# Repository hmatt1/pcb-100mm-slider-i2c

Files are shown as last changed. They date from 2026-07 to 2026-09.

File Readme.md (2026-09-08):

# pcb-100mm-slider-i2c

Preface:

> Hi everyone!
>
> This blog post explains how to make a PCB from scratch.
>
> It is pretty detailed on the technical side, with a goal of demistifying a lot about hardware.
>
> It also talks about my experience working with [PCBWay](https://www.pcbway.com/), who was kind enough to fund this project. They were supportive and gave me lots of freedom too. PCBWay was a great
> way to get my custom PCB design turned into reality, so I included a lot of detail on how that is done to hopefully help anyone who is new to PCB design.
>
> Thanks for reading and I hope you enjoy :) 

----

# Building a slider PCB from scratch

This [slider](https://www.adafruit.com/product/5295) from Adafruit is cool, but it has a problem. It is too small.

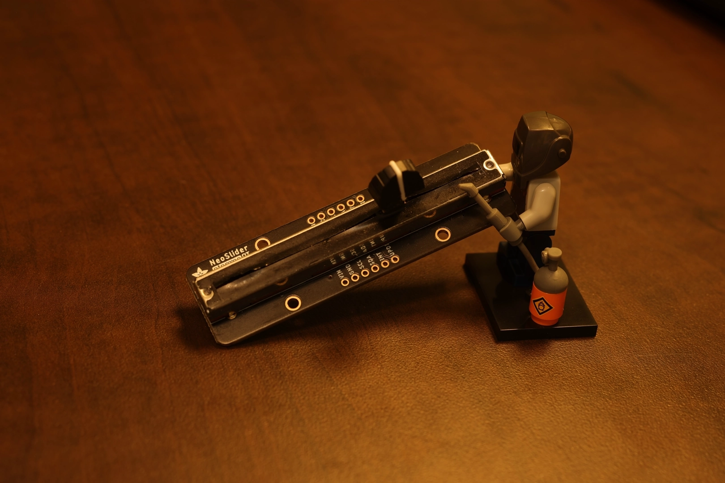
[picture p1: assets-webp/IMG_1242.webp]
Adafruit Sliders


It only has 65mm of travel distance for the slider movement.

Fortunately, it was easy to find a longer slider.

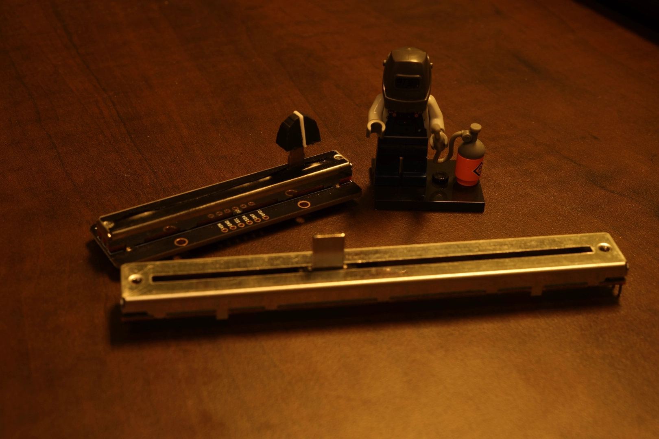
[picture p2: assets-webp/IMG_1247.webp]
new slider


This is the PTB0143-2010BPA103, in Bourn's PTB Series. It is a Low Profile Slide Potentiometer.

It has a whopping 100mm of travel! Here are some other specs:

Resistance: 10 kOhms
Tolerance: 20%	
Taper: Linear
Life: 15,000 Cycles

15k cycles is pretty nice! I've already used 3 of them. 14,997 until it starts to wear out! Wahoo!

It's an awesome part, but we still have a problem. It's not attached to a PCB, so it doesn't have an I2C interface to actually start working with it.

So obviously, I'm going to have to build that part myself. Fortunately, we have a great path forward.

After my [last blog post](https://hackaday.io/project/205240-usb-to-i2c-demo), [Aran](https://x.com/pcbway_aran) from [PCBWay](https://www.pcbway.com/) messaged me to see if [PCBWay](https://www.pcbway.com/) could sponsor my next project. 

**This was a really delightful surprise!**

I never expected to get that kind of recognition for my [last project](https://hackaday.io/project/205240-usb-to-i2c-demo). Also, I do often see [PCBWay](https://www.pcbway.com/) sponsoring YouTubers that I like, so I was excited that they reached out.

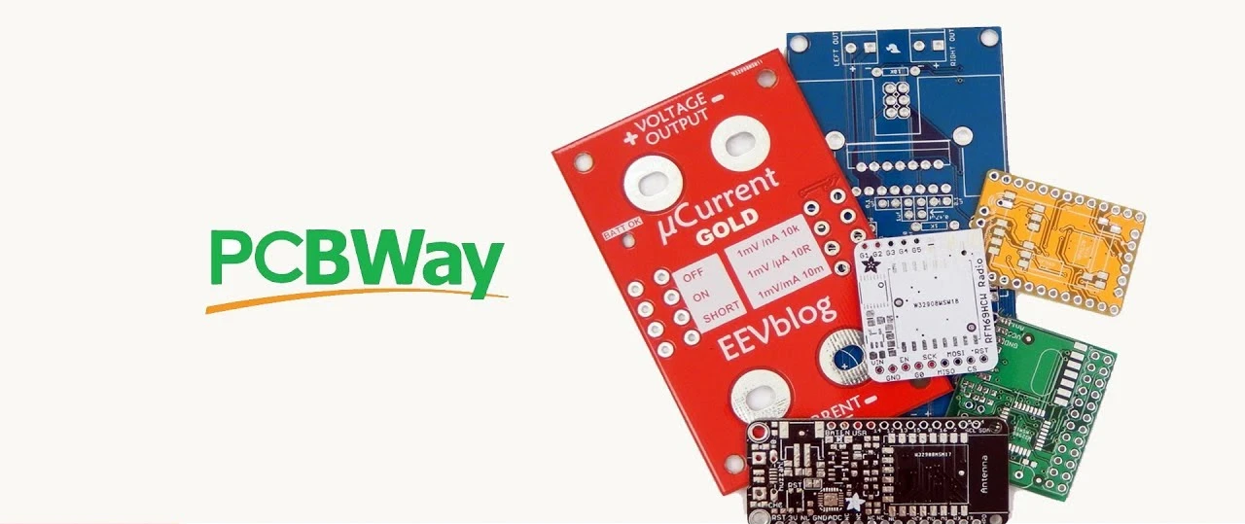
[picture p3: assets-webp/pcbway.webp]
pcbway


There's a lot to explain before we can send the design to PCBWay.

The first thing to cover is how a potentiometer works.

And to understand that, let's review a simple voltage divider.

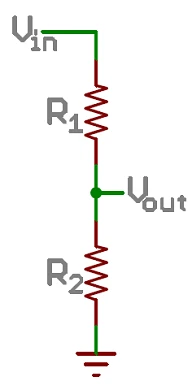
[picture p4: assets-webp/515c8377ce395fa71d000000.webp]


The formula is:

```
Vout = Vin*R2/(R1+R2) 
```

So it lets you split voltages over resistors in series.

Here is an example with some voltage numbers.

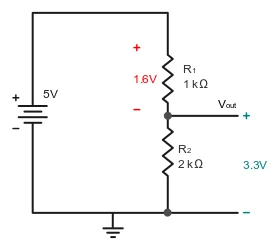
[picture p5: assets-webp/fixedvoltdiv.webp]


A slide potentiometer is basically just a variable resistor. So it is a resistor that goes between 0 and 10k ohms as you slide it.

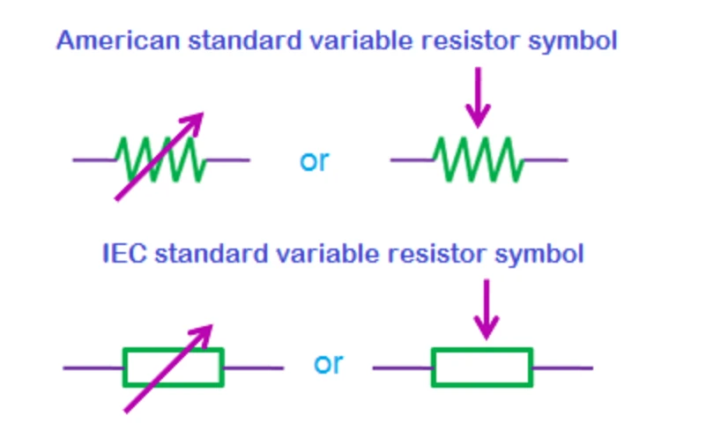
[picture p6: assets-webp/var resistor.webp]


They even show circuit diagrams like these straight in the [Bourns slider datasheet.](https://www.bourns.com/docs/Product-Datasheets/PTB.pdf)

I drew this diagram to help compare.

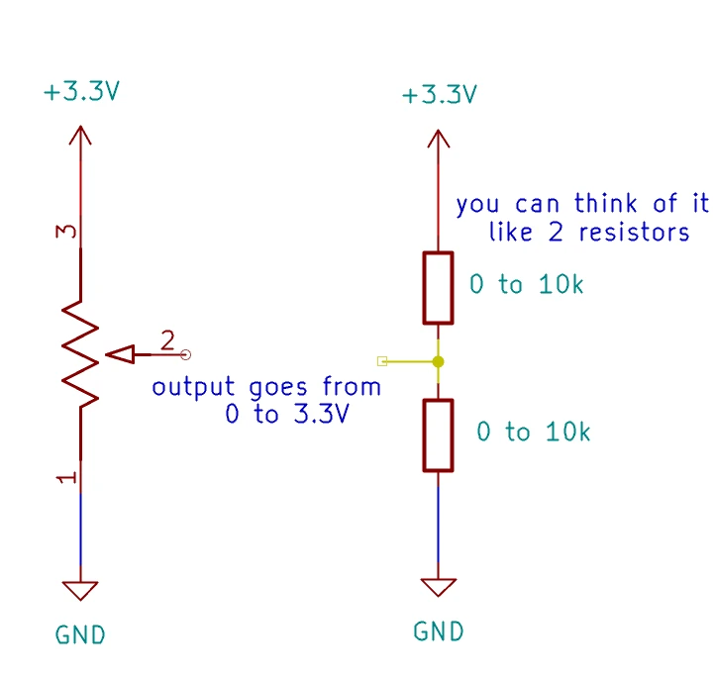
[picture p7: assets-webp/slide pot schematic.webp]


In the above image, the two resistors would always add up to 10k in total. I just didn't have a good way to represent that in the drawing.

Now that we understand the voltage divider, the next step is to add a capacitor between the wiper and ground to filter out noise.

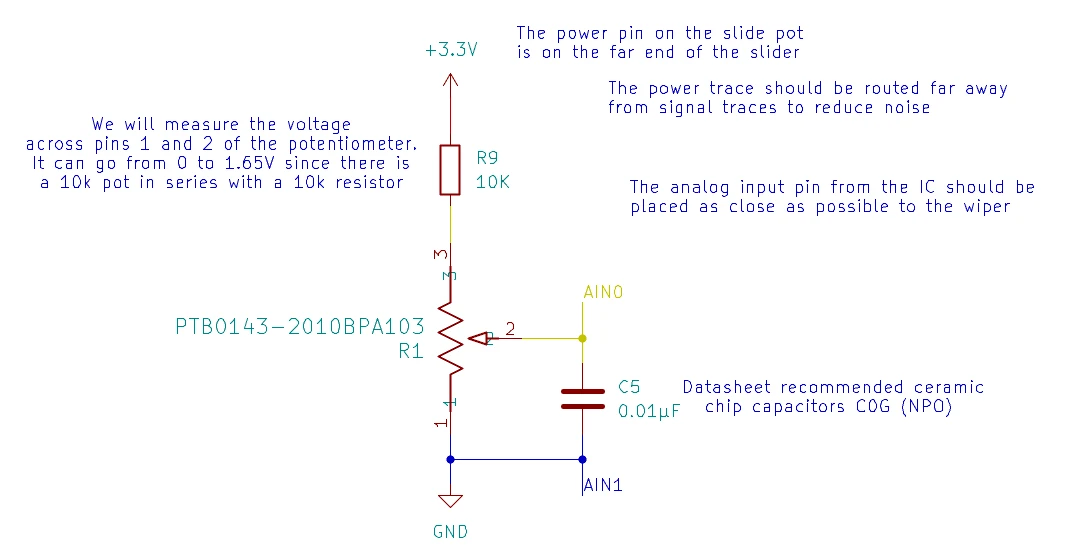
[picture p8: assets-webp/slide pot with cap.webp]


And I'm sure you're wondering now, what is the other 10k resistor doing in parallel with the circuit?

It's a long story and I'm not sure I even got it right.

First, it's nice to have a resistor in series with a slide pot, because when the wiper is all the way at one end, the resistance is 0 and it's connected to power, so there would be nothing limiting current in the case of a short due to a mistake in the circuit. It probably only needs to be 1k instead of 10k in that case.

It would have been a nice idea to add an optional jumper to bypass that resistor. But now that I think about it, I could pry it off the board and solder the pads together. Yeah, that would work fine if I want to experiment without it!

Second, which is also the main reason it's useful, is being able to use the slide pot as a rheostat instead of a voltage divider. To create a rheostat, you short the wiper to pin 3 of the slide pot. I didn't really find great explanations of this, and ended up getting confused and forgot to add a trace with a jumper to be able to try it in my circuit.

More importantly, I vibe coded this beautiful web demo to illustrate the difference (works better on desktop). Not 100% sure if the numbers it shows are right, but it's a good illustration of how the current flows.

----- DEMO HERE!!!! TODO ------

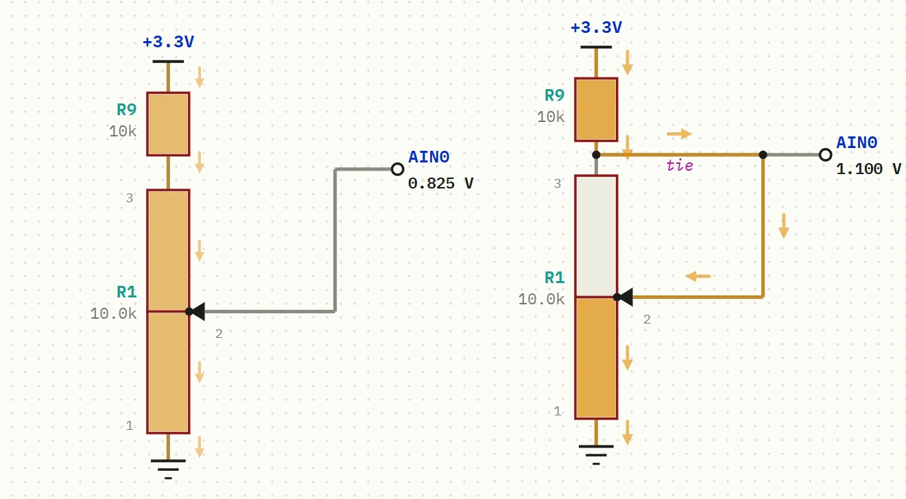
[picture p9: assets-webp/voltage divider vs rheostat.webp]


Looking back, it would have been really great to make this easier to switch between these two configurations on the final circuit! A good lesson learned.

So now that we understand how the slide potentiometer works, what do we do with it?

The answer is simple. We connect AIN0 to an ADC (Analog to Digital converter).

There's tons to choose from, but I decided to use the ADS112C04 from Texas Instruments.

Link: https://www.ti.com/product/ADS112C04

The important part was these specs:

| Parameter | Value |
|---|---|
| Resolution (Bits) | 16 |
| Sample rate (max) (ksps) | 2 |
| Interface type | I2C |
|Digital supply (min) (V) | 2.3 |
|Digital supply (max) (V) |	5.5 |

This means we can have 2,000 readings per second, which is .5ms response time to the slider moving.

I2C is a super convenient interface for connecting to the chip.

3.3V power fits comfortably in the digital voltage range for the chip.

And finally, the resolution of 16 bit readings is completely overkill. Which is exactly what I wanted!

This basically means the max value from the ADC would be 65,535. 

Remember, the slider is 100mm long.

So in a perfect world, that means if you move the slider 0.00152590219 millimeters, that would equate to changing the digital value by 1.

The real world has a lot more noise obviously.

**I love the idea that moving the slider less than .01mm would be picked up by your computer in less than 1ms.**

Now we have our chip, we need to hook it up to the rest of the circuit:

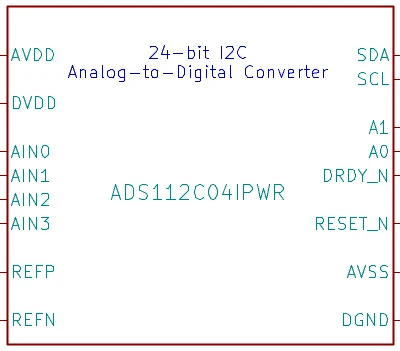
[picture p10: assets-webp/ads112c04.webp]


The analog inputs are pretty easy to connect. AIN0 will go to the wiper of the slide pot, and the rest we just tie to ground. We aren't going to both with AIN2 and AIN3 in this design, and we will just measure the voltage between AIN0 and AIN1.

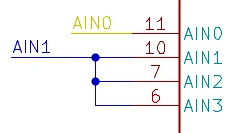
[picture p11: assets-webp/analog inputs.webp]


Next we have some data lines.

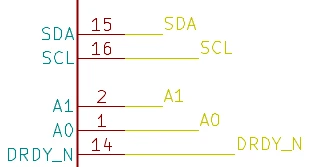
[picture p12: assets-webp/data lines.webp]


which will connect to the socket.

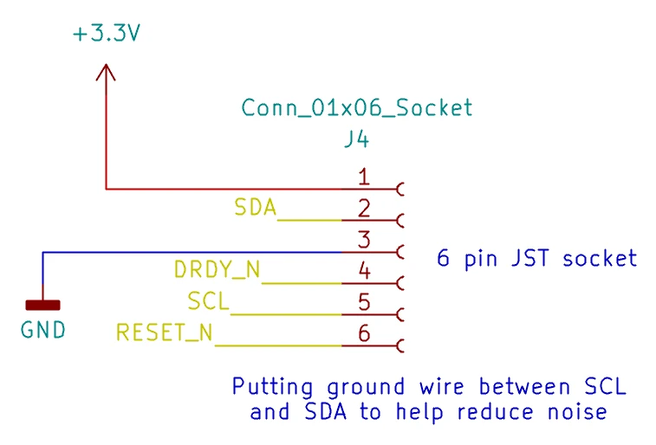
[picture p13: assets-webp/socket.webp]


The datasheet said these should be connect to power with 1k pull-up resistors. And a capacitor was added between power and ground to help with filtering noise.

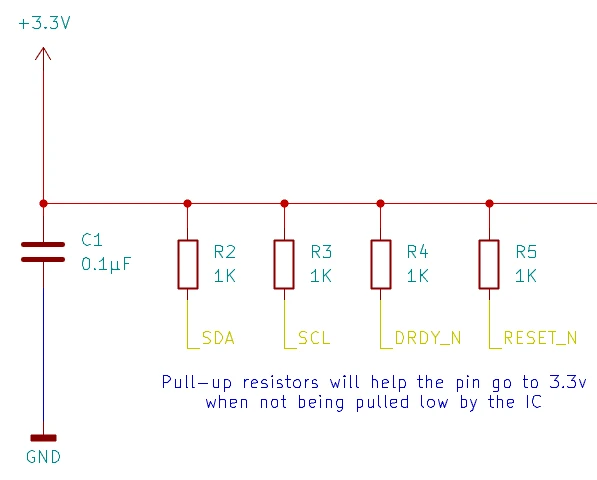
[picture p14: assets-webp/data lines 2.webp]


I also set up some jumpers to be able to configure the I2C address of the board.

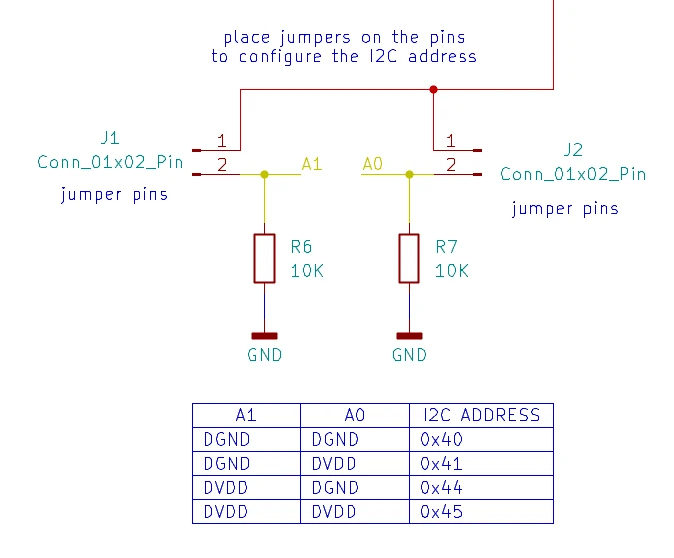
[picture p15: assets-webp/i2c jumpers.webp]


So in the full schematic, I included these tips I found in my research.

> PCB Habits for 2-layer boards:
>
> - Use 6 mil wide signal trace, 20 mil wide power traces and 13 mil drilled diameter
> - Route components, signals and power paths on layer 1 and a ground plane on layer 2
> - Adjust components for less congested routing and space signal traces far apart
> - When you need to route a cross-under on the bottom layer, make it short. When you can't make it short, add a return strap over it
> - Place decoupling capacitors as close to the power pin of the IC and with as low a loop inductance as practical
> - Use the largest size capacitor in the smallest body with a voltage rating at least 2x the intended rail application. This is usually a 22 uF MLCC capacitor.
> - On all connectors, try to allocate one return for each digital signal, if possible

And here is everything all put together!

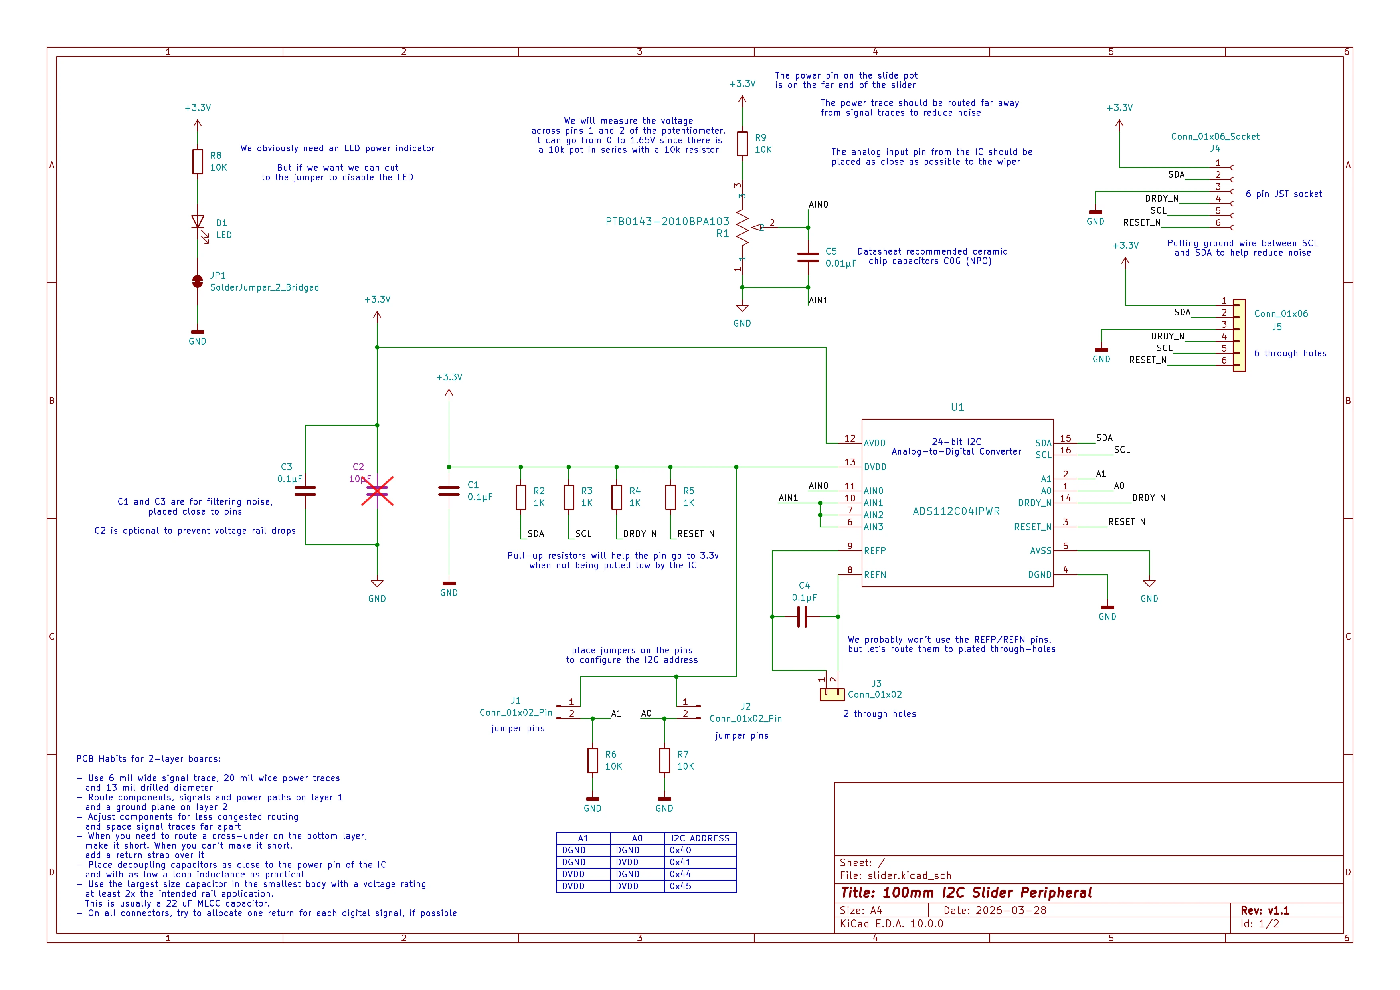
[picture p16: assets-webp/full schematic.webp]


The next thing we need to do is pick out the actually parts we want to use to mark the board. That means picking out exactly which capacitor, which resistor, etc.

I found that [partsbox](https://partsbox.com/) is free and is pretty useful to document the list of parts.

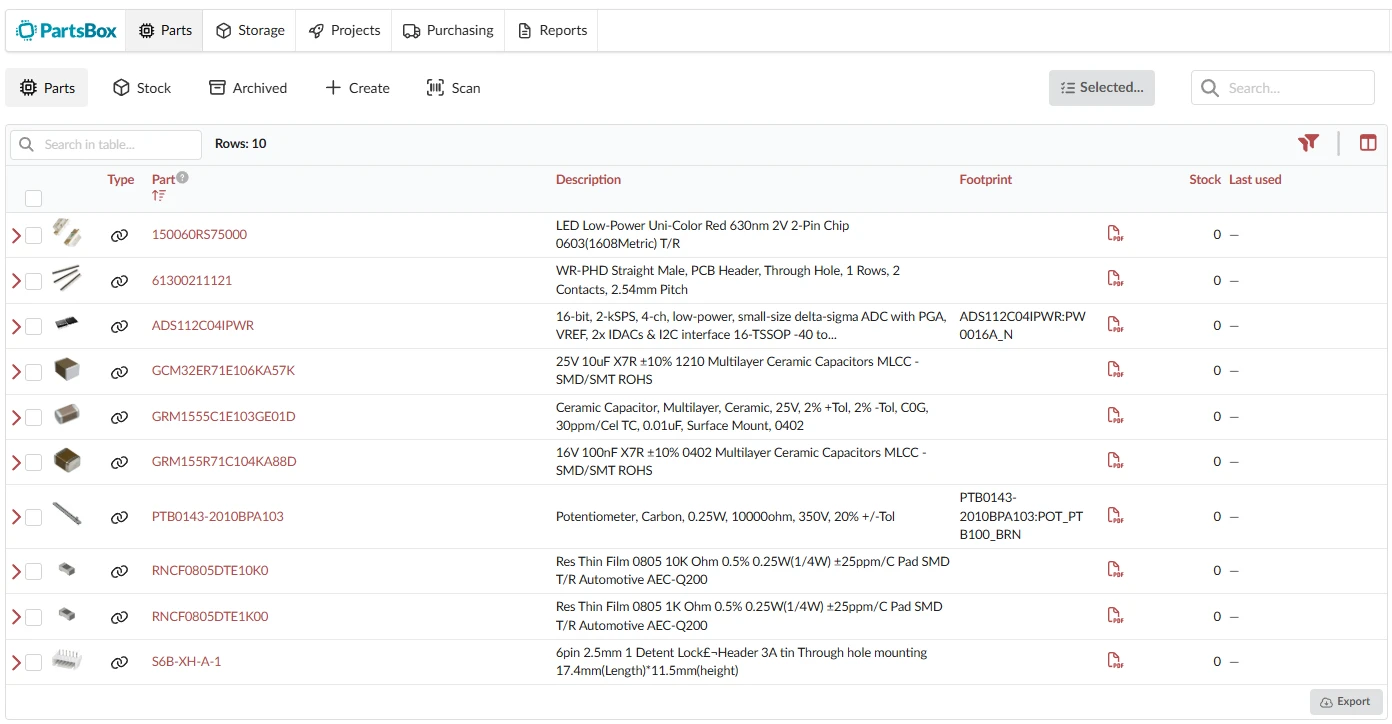
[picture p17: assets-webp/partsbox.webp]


Pretty much when I was looking for parts, I would dig through Digikey and Mouser to filter and see what parts are popular for the category.

But I also really wanted to use some super tiny capacitors on the PCB.
They are better for causing less interference in the circuit, and letting you have shorter distance between components. Also, TI specifically recommended ceramic capacitors to use with the ADC.

I found GRM1555C1E103GE01D from Murata, which is a  0.01uF, surface mount, Multilayer Ceramic Capactior. Specifically, it uses the 0402 footprint, which is about 1mm square.

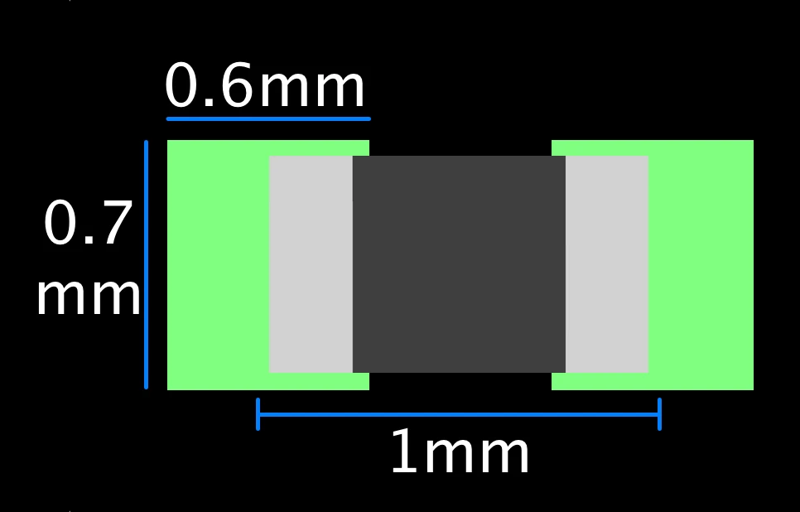
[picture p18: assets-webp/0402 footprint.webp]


It's actually amazing that [PCBWay](https://www.pcbway.com/) will solder these tiny capacitors perfectly for you. So I can use them freely on my board, and I don't have to deal with soldering them by hand.

The next part is laying out the PCB with KICAD. I can't remember if I used an AI summary or found a blog post or what for these layout guidelines, or I might have just pieces bullet points together from different sources. But it definitely help me along the way!

> **Layout Guidelines**
>
> Employing best design practices is recommended when laying out a printed-circuit board (PCB) for both analog and digital components. This recommendation generally means that the layout separates analog components [such as ADCs, amplifiers, references, digital-to-analog converters (DACs), and analog MUXs] from digital components [such as microcontrollers, complex programmable logic devices (CPLDs), field-programmable gate arrays (FPGAs), radio frequency (RF) transceivers, universal serial bus (USB) transceivers, and switching regulators]. Figure 82 shows an example of good component placement. Although Figure 82 provides a good example of component placement, the best placement for each application is unique to the geometries, components, and PCB fabrication capabilities employed. That is, there is no single layout that is perfect for every design and careful consideration must always be used when designing with any analog component.
>
> The following basic recommendations for layout of the ADS112C04 help achieve the best possible performance of the ADC. A good design can be ruined with a bad circuit layout.
>
> Separate analog and digital signals. To start, partition the board into analog and digital sections where the layout permits. Routing digital lines away from analog lines prevents digital noise from coupling back into analog signals.
>
> The ground plane can be split into an analog plane (AGND) and digital plane (DGND), but is not necessary. Place digital signals over the digital plane, and analog signals over the analog plane. As a final step in the layout, the split between the analog and digital grounds must be connected to together at the ADC.
>
> Fill void areas on signal layers with ground fill.
>
> Provide good ground return paths. Signal return currents flow on the path of least impedance. If the ground plane is cut or has other traces that block the current from flowing right next to the signal trace, another path must be found to return to the source and complete the circuit. If forced into a larger path, the chance that the signal radiates increases. Sensitive signals are more susceptible to EMI interference.
>
> Use bypass capacitors on supplies to reduce high-frequency noise. Do not place vias between bypass capacitors and the active device. Placing the bypass capacitors on the same layer as close to the active device yields the best results.
>
> Consider the resistance and inductance of the routing. Often, traces for the inputs have resistances that react with the input bias current and cause an added error voltage. Reducing the loop area enclosed by the source signal and the return current reduces the inductance in the path. Reducing the inductance reduces the EMI pickup and reduces the high-frequency impedance at the input of the device.
>
> Watch for parasitic thermocouples in the layout. Dissimilar metals going from each analog input to the sensor can create a parasitic thermocouple that can add an offset to the measurement. Differential inputs must be matched for both the inputs going to the measurement source.
>
> Analog inputs with differential connections must have a capacitor placed differentially across the inputs. Best input combinations for differential measurements use adjacent analog input lines (such as AIN0, AIN1 and AIN2, AIN3). The differential capacitors must be of high quality. The best ceramic chip capacitors are C0G (NPO) that have stable properties and low noise characteristics.

and more guidelines specific to our chip:

> **ADS112C04 layout recommendations**
>
> - Separate analog and digital signals. Partition the board into analog and digital sections where the layout permits.
> - The ground plane can be split into AGND and DGND, but is not necessary. Connect the split together at the ADC as a final step.
> - Fill void areas on signal layers with ground fill.
> - Provide good ground return paths. Return current forced into a larger loop increases radiation and EMI susceptibility.
> - Use bypass capacitors on supplies. No vias between the bypass capacitor and the active device, same layer, as close as possible.
> - Consider trace resistance and inductance. Input trace resistance reacts with input bias current and adds an error voltage.
> - Watch for parasitic thermocouples. Match the dissimilar-metal transitions on both differential inputs.
> - Place a differential capacitor across differential inputs. Use adjacent input pairs (AIN0/AIN1, AIN2/AIN3) and C0G (NPO) dielectric.

-----

Anyway, in Kicad, you want to set up each part in the schematic with the symbol properties.

So if I a want to assign C1 to a part, I would open up symbol properties and fill them out.

It looks like this:

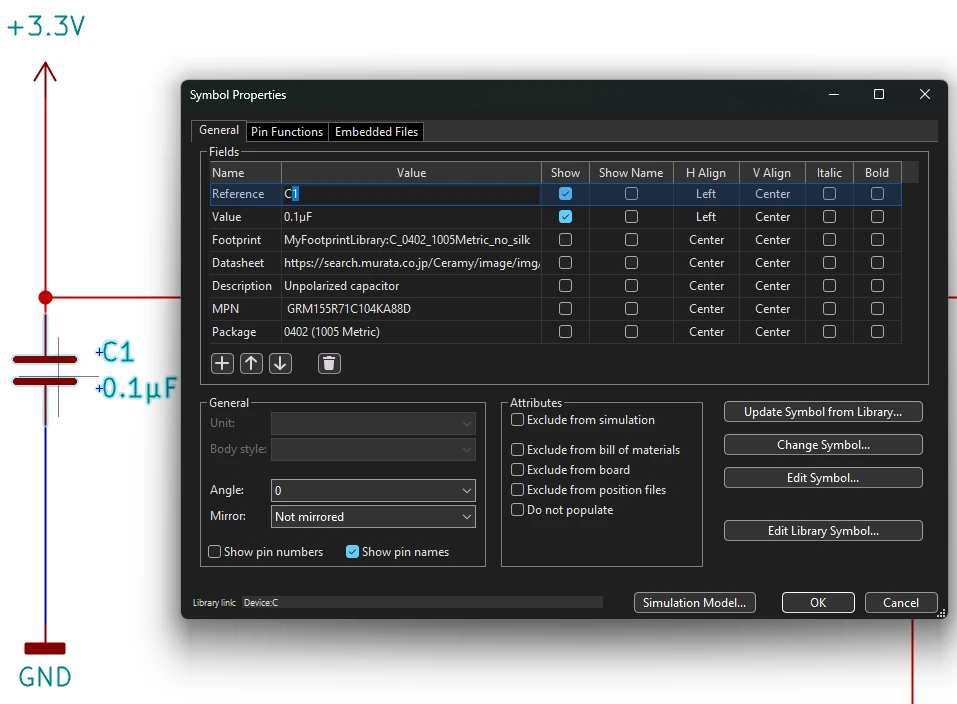
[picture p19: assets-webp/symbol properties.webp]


This is super important because it will know what footprints to use with which parts of the schematic. And it will let the PCBWay Kicad plugin export the BOM automatically. But more on that later!

So basically, we are tying these things together:

```
Schematic Symbol -> Part Number -> Footprint 
```

So if you look at the menu in Kicad, it should start making sense.

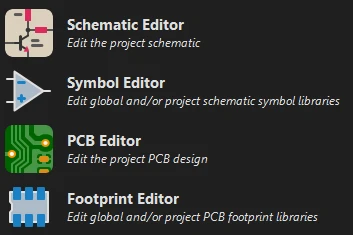
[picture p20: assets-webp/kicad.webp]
kicad


Schematic is the actual diagram. Symbols are symbols on the diagram. Footprints are the geometry that will attach specific parts to the board.

And then PCB Editor is the fun part, where we design the layout of the board itself.

You import the schematic into the PCB Editor, and then draw traces (wires) to connect everything together.

Kicad already knows how your schematic is set up, so it makes sure you can't accidentally connect things that aren't connected in the schematic.

Before you jump into creating the whole PCB design, you need to set up the design rules.

PCBWay has a nice article about Design Rules, and even have the files available to download and import the rules into Kicad.

[PCBWay Design Rules](https://www.pcbway.com/pcb_prototype/PCB_Design_Rule_Check.html)

You'll also want to pay attention to what your manufacturer has available, so you can make sure the rules are correct for that too.

For example, PCBWay lets you select the min spacing and min hole size when [ordering online](https://www.pcbway.com/orderonline.aspx).



So if your min hole size is .3mmm, you don't want to design a PCB with smaller holes  than that. Basically, you want to know all the dimensions of everything in your design.

I think it's a really good idea to pick which manufacturer you want to make your PCB before doing the design. Read through all the options available, so you can ensure your design will meet what they are capable of building.

If you think back to the 1mm capacitor I picked out as a part, not everyone is going to be able to solder that to a board. 

I did look up the [assembly capabilities](https://www.pcbway.com/pcb_prototype/PCB_assembly_Capabilities.html) for PCBWay, to verify this in the documentation:

> we can accept components as small as 01005, 0201,0402.

This means they will deal with my super tiny capacitor! I do not want to try to solder that.

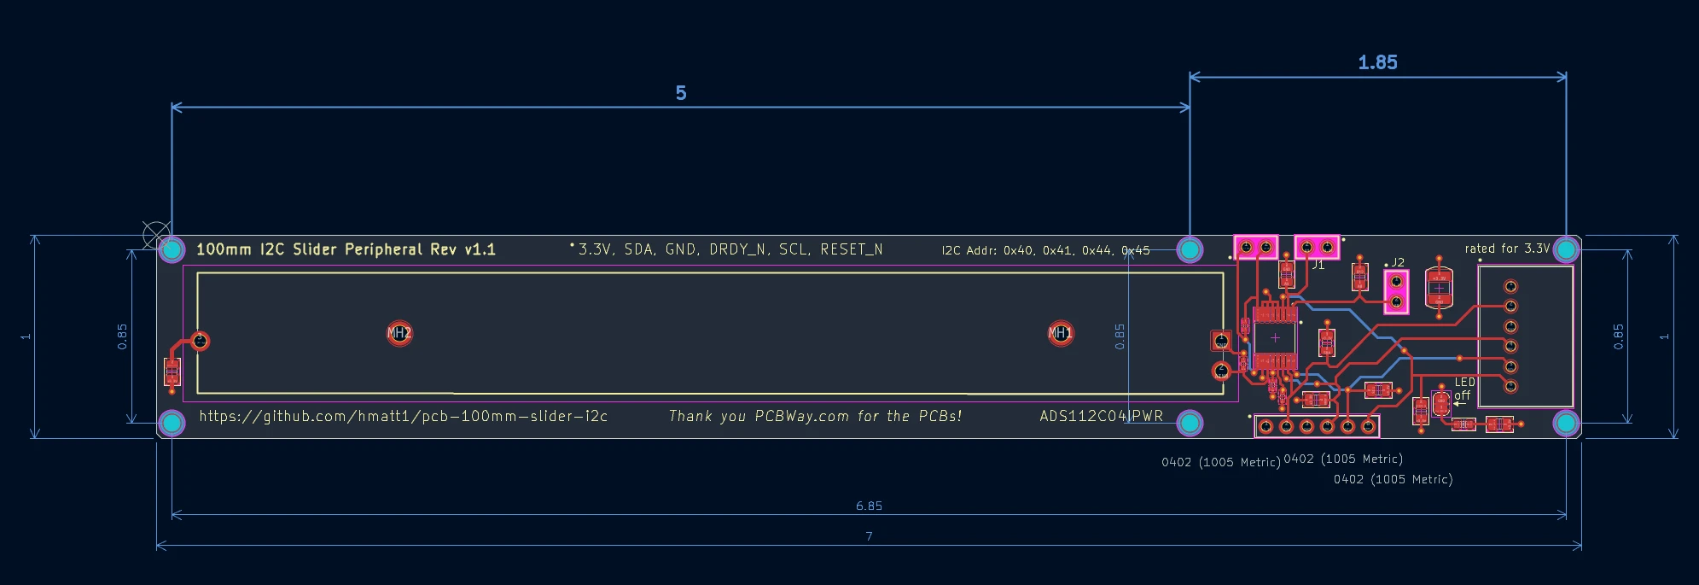
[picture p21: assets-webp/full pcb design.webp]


And here is the rendered version:

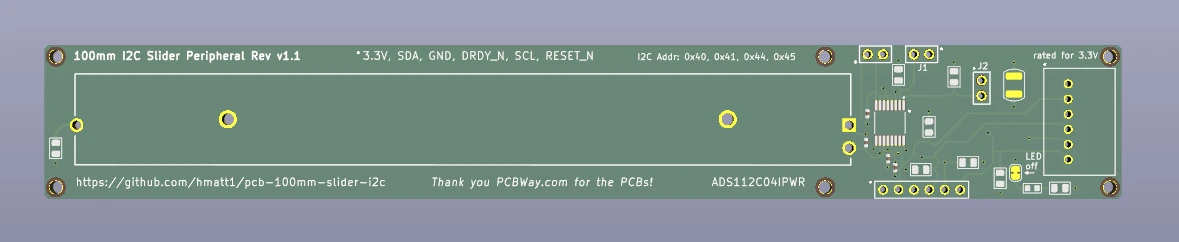
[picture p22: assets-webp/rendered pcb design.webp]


You can do 3D models of the parts too, but I decided to skip that and trust the footprints. It is a good idea though if you want to take time to verify things will fit together properly in real life.

For exporting files for PCBWay, you can use the [PCBWay Fabrication Toolkit plug-in for Kicad](https://github.com/pcbway/PCBWay-Plug-in-for-Kicad).

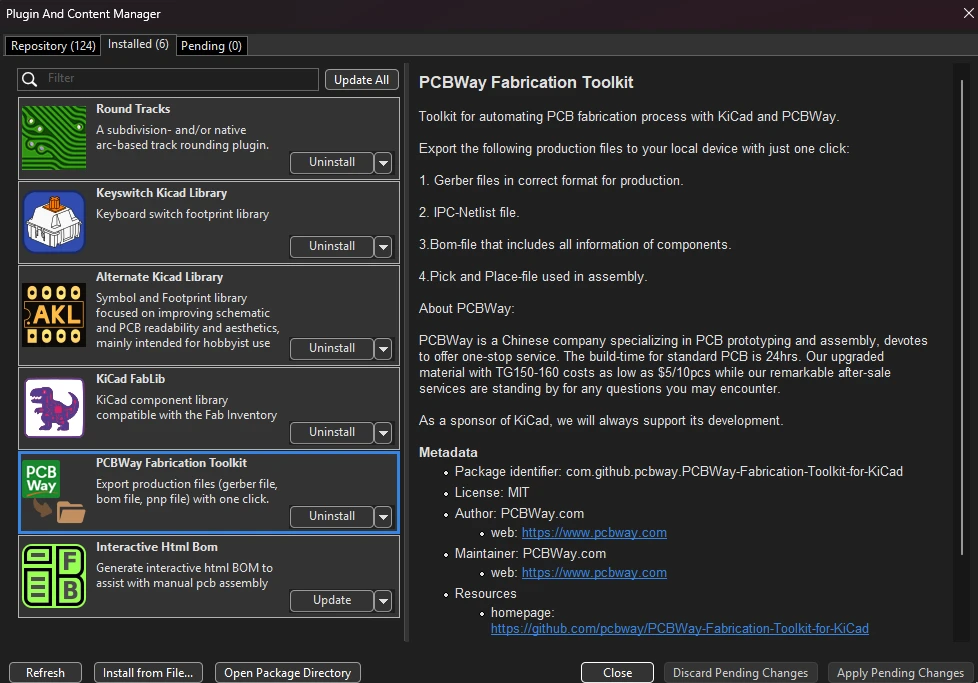
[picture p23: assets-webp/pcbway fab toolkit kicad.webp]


You can use when you're in the PCB Editor from the Tools menu.

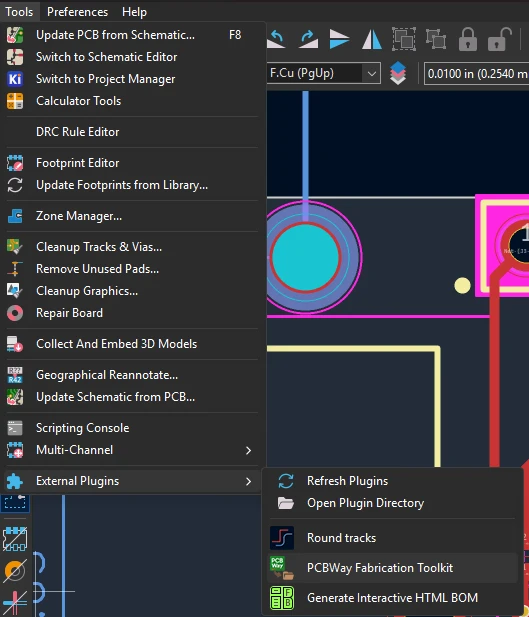
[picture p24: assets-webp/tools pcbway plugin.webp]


One click and it will export all the files you need.

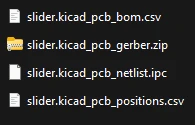
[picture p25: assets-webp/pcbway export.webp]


Just upload the files to PCBWay and you're good to go.

I'll share what my order looked like here too:

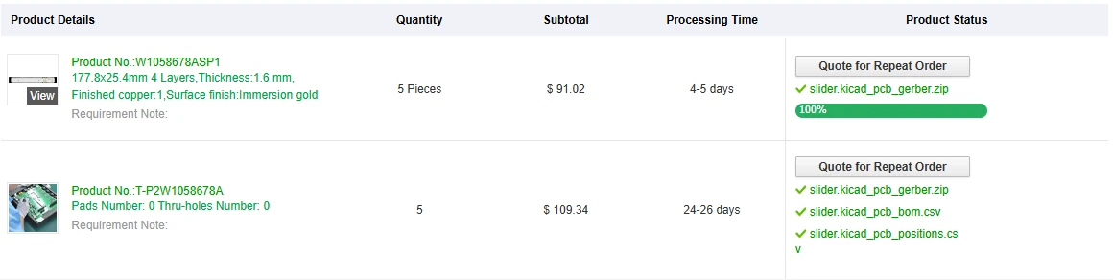
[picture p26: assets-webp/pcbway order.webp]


The order includes all the parts and assembly too. I will be getting 5 boards, fully assembled, ready to test out as soon as they arrive at my house! I don't have to mess with any soldering and PCBWay went through the work of sourcing all the different parts. By the way, I did only use [Digikey](https://www.digikey.com/) to find what parts they have in stock. PCBWay ordered parts directly from them for my board, and that was included in the cost of the order.

It was nice that I could just focus on the design.

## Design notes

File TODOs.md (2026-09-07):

  Here is your master checklist of everything left to do to wrap up the blog post:

  ### 📝 Blog Post & Content TODOs

  [ ] Embed the Interactive Demo: Replace the ----- DEMO HERE!!!! TODO ------ marker at line 108 with the index.html
  React demo we polished up.
  [ ] Write the Software/Testing Section: The post currently ends after the PCBWay order. Write a new section
  explaining how you hooked it up to your computer.
  [ ] Add Python Script Snippet: Include the Python code you used to read the I2C data from the ADC.
  [ ] Add a Conclusion: Write a wrap-up paragraph showing that the slider works, summarizing the <1ms / 16-bit
  accuracy results you hyped up earlier, and thanking the reader/PCBWay.
  [ ] Add https://kicanvas.org to host it

  ### 📸 Photography Checklist

  [ ] The Batch Shot: A picture of all 5 assembled boards laid out together (the classic "they arrived!" shot).
  [x] The "Hero" Shot: A nice, clean shot of a single fully assembled PCB with the massive 100mm Bourns slider
  attached.
  [x] The 0402 Capacitor Closeup: A macro shot of the tiny 1mm capacitor (put a coin, ruler, or pen tip next to it
  for scale to show off the assembly job).
  [x] The ADC Chip (ADS112C04): A closeup of the Texas Instruments chip soldered onto the board.
  [x] The I2C Address Jumpers: A photo showing the jumper pads, ideally with one bridged with solder to show how you
  configure the address.
  [x] The "Action" Shot: A photo of the board wired up and plugged into your computer/microcontroller setup to
  introduce the Python software section.
  [x] Python Output Screenshot: A screenshot of your terminal/console showing the live data streaming in from the
  slider.

  ### Sharing

  [ ]  Hackaday post
  [ ]  Reddit post
  [ ]  PCBWay review
  [ ]  OSHWA Certification

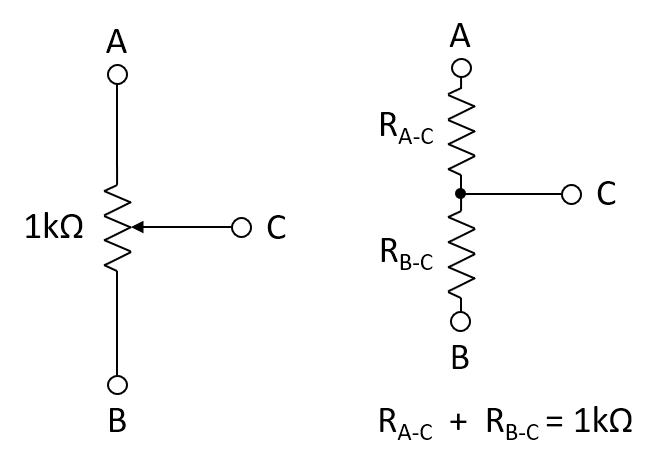
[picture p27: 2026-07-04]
assets/potentiometer-symbol-2.png

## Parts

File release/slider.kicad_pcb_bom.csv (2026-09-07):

Designator | Quantity | Value | Footprint | Package | MPN | DNP | Mount_Type | Description | KiLib_Generator | Sim.Pins
C1, C3, C4 | 3 | 0.1µF | C_0402_1005Metric_no_silk | 0402 (1005 Metric) | GRM155R71C104KA88D |  | smt | Unpolarized capacitor | SMD_2terminal_chip_molded
C5 | 1 | 0.01µF | C_0402_1005Metric_no_silk | 0402 (1005 Metric) | GRM1555C1E103GE01D |  | smt | Unpolarized capacitor | SMD_2terminal_chip_molded
D1 | 1 | LED | LED_0603_1608Metric | 0603 (1608 Metric) | 150060RS75000 |  | smt | Light emitting diode |  | 1=K 2=A
J1, J2 | 2 | Conn_01x02_Pin | 61300211121 | Through Hole | 61300211121 |  | tht | Generic connector, single row, 01x02, script generated
J4 | 1 | Conn_01x06_Socket | CONN_S6B-XH-A-1_JST | Through Hole | S6B-XH-A-1 |  | tht | Generic connector, single row, 01x06, script generated
R1 | 1 | PTB0143-2010BPA103 | PTB01432010BPB103 | Through Hole | PTB0143-2010BPA103 |  | tht
R2, R3, R4, R5 | 4 | 1K | R_0805_2012Metric | 0805 (2012 Metric) | RNCF0805DTE1K00 |  | smt | Resistor
R6, R7, R8, R9 | 4 | 10K | R_0805_2012Metric | 0805 (2012 Metric) | RNCF0805DTE10K0 |  | smt | Resistor
U1 | 1 | ADS112C04IPWR | SOP65P640X120-16N | TSSOP (16) | ADS112C04IPWR |  | smt

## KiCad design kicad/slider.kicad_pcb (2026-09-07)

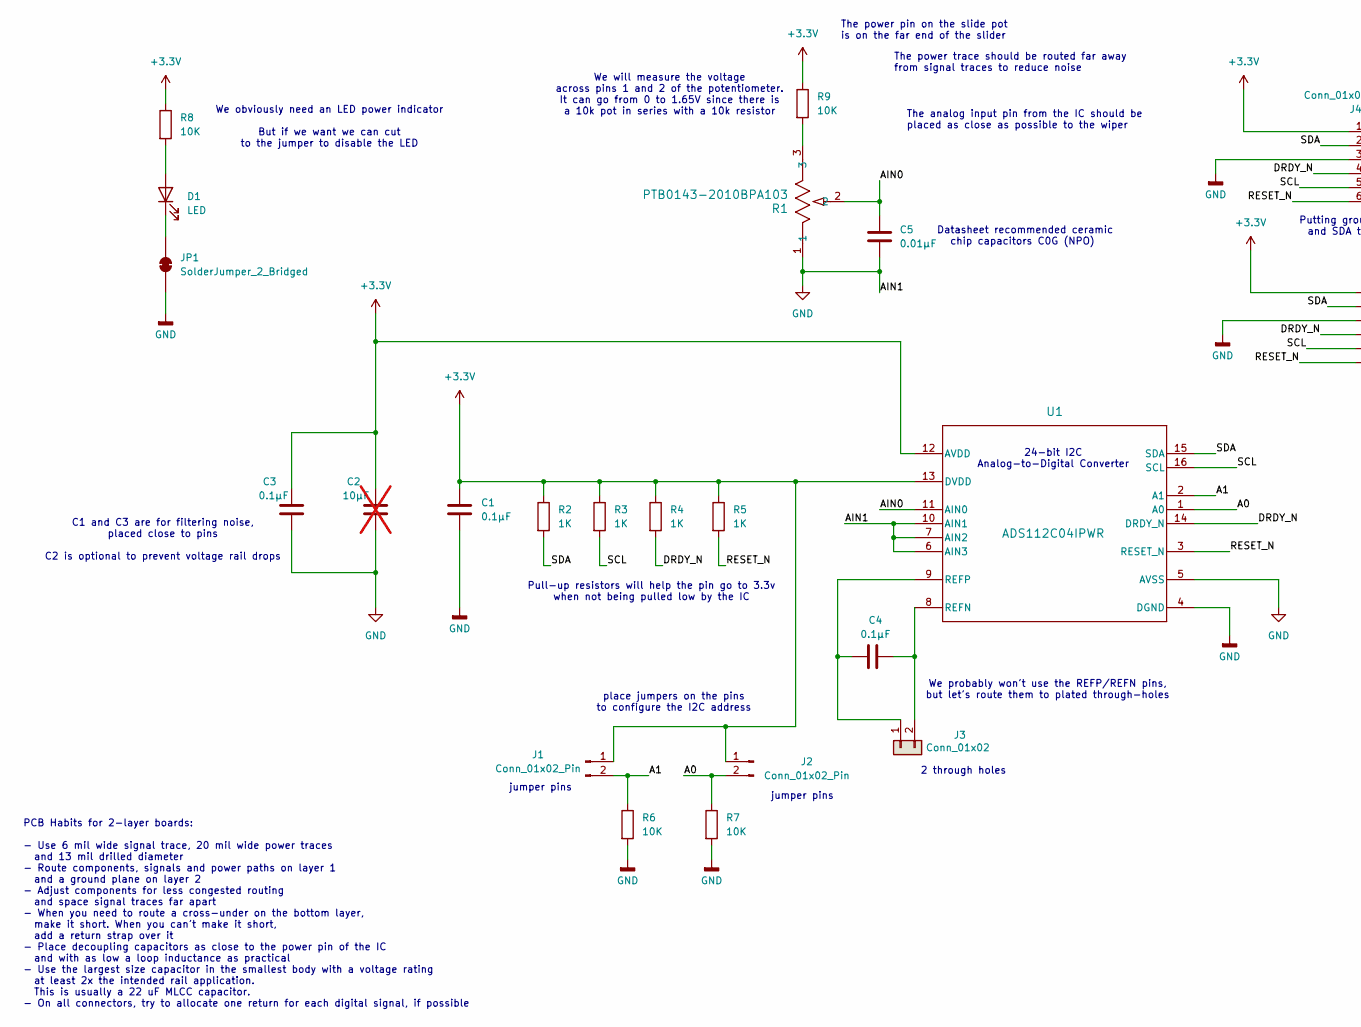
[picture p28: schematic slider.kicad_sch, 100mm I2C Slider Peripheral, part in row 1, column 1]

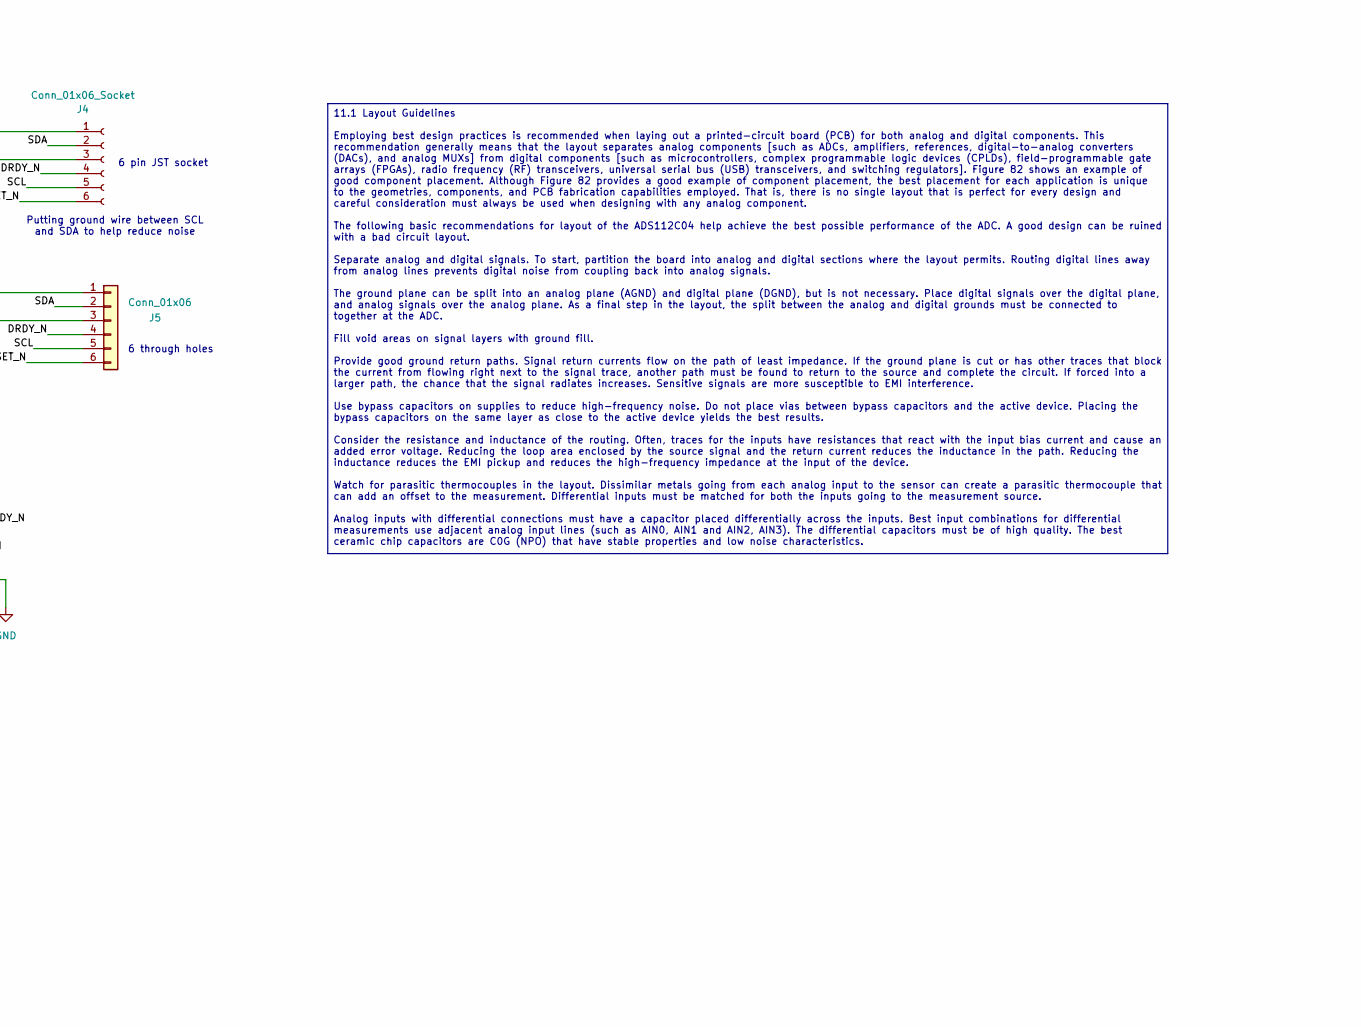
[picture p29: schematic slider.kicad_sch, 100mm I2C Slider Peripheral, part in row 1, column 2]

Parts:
C1, C3, C4: 0.1µF; C_0402_1005Metric_no_silk; MPN GRM155R71C104KA88D
C2: 10µF; C_1210_3225Metric; MPN GCM32ER71E106KA57K; not fitted
C5: 0.01µF; C_0402_1005Metric_no_silk; MPN GRM1555C1E103GE01D
D1: LED; LED_0603_1608Metric; MPN 150060RS75000
J1, J2: Conn_01x02_Pin; 61300211121; MPN 61300211121
J3: Conn_01x02; 61300211121
J4: Conn_01x06_Socket; CONN_S6B-XH-A-1_JST; MPN S6B-XH-A-1
J5: Conn_01x06; CONN06_6130_15P24X2P54_WRE
JP1: SolderJumper_2_Bridged; SolderJumper-2_P1.3mm_Bridged_RoundedPad1.0x1.5mm
R1: PTB0143-2010BPA103; PTB01432010BPB103; MPN PTB0143-2010BPA103
R2, R3, R4, R5: 1K; R_0805_2012Metric; MPN RNCF0805DTE1K00
R6, R7, R8, R9: 10K; R_0805_2012Metric; MPN RNCF0805DTE10K0
U1: ADS112C04IPWR; SOP65P640X120-16N; MPN ADS112C04IPWR

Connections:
+3.3V: C1.1, C2.1, C3.1, J1.1, J2.1, J4.1, J5.1, R2.1, R3.1, R4.1, R5.1, R8.1, R9.1, U1.12 (AVDD), U1.13 (DVDD)
/A0: J2.2, R7.1, U1.1 (A0)
/A1: J1.2, R6.1, U1.2 (A1)
/AIN0: C5.2, R1.2, U1.11 (AIN0)
/DRDY_N: J4.4, J5.4, R4.2, U1.14 (DRDY_N)
/RESET_N: J4.6, J5.6, R5.2, U1.3 (RESET_N)
/SCL: J4.5, J5.5, R3.2, U1.16 (SCL)
/SDA: J4.2, J5.2, R2.2, U1.15 (SDA)
GND: C1.2, C2.2, C3.2, C5.1, J4.3, J5.3, JP1.2 (B), R1.1, R6.2, R7.2, U1.4 (DGND), U1.5 (AVSS), U1.6 (AIN3), U1.7 (AIN2), U1.10 (AIN1)
unnamed: D1.2 (A), R8.2
unnamed: D1.1 (K), JP1.1 (A)
unnamed: C4.1, J3.1, U1.9 (REFP)
unnamed: C4.2, J3.2, U1.8 (REFN)
unnamed: R1.3, R9.2

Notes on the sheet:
C1 and C3 are for filtering noise, placed close to pins C2 is optional to prevent voltage rail drops
Pull-up resistors will help the pin go to 3.3v when not being pulled low by the IC
The analog input pin from the IC should be placed as close as possible to the wiper
place jumpers on the pins to configure the I2C address
2 through holes
Putting ground wire between SCL and SDA to help reduce noise
jumper pins
6 pin JST socket
We probably won't use the REFP/REFN pins, but let's route them to plated through-holes
The power trace should be routed far away from signal traces to reduce noise
We will measure the voltage across pins 1 and 2 of the potentiometer. It can go from 0 to 1.65V since there is a 10k pot in series with a 10k resistor
6 through holes
The power pin on the slide pot is on the far end of the slider
We obviously need an LED power indicator But if we want we can cut to the jumper to disable the LED
PCB Habits for 2-layer boards: - Use 6 mil wide signal trace, 20 mil wide power traces and 13 mil drilled diameter - Route components, signals and power paths on layer 1 and a ground plane on layer 2 - Adjust components for less congested routing and space signal traces far apart - When you need to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
24-bit I2C Analog-to-Digital Converter
Datasheet recommended ceramic chip capacitors C0G (NPO)
11.1 Layout Guidelines Employing best design practices is recommended when laying out a printed-circuit board (PCB) for both analog and digital components. This recommendation generally means that the layout separates analog components [such as ADCs, amplifiers, references, digital-to-analog conver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

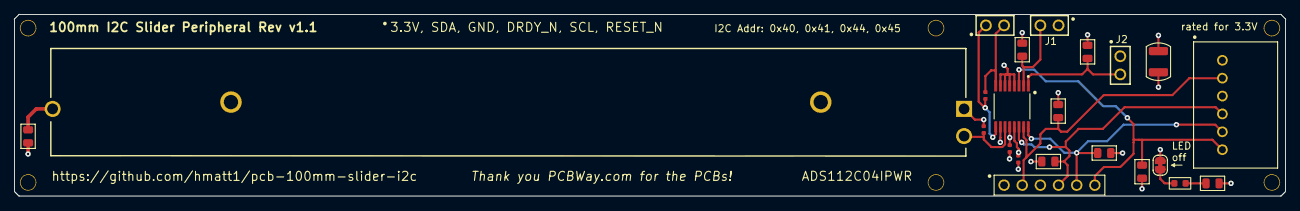
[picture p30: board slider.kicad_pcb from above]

Board: 4 copper layers, 177.8 x 25.4 mm, 28 parts (0 on the bottom side), 14 nets.

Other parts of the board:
REF1**, REF2**, REF3**, REF4**, REF5**, REF6**: MountingHole_M2_new

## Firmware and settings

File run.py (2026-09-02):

# go read https://github.com/hmatt1/adafruit-FT232H-my-demo to learn how to set this up!

import usb

print("usb:")
dev = usb.core.find(idVendor=0x0403, idProduct=0x6014)
print(dev)

from pyftdi.ftdi import Ftdi

# Just to display debugging info
#print("ftdi:")
#Ftdi().open_from_url('ftdi:///?')

def lower_ftdi_latency(i2c, ms=1):
    seen = set()
    stack = [i2c]
    while stack:
        obj = stack.pop()
        if id(obj) in seen:
            continue
        seen.add(id(obj))
        if hasattr(obj, "set_latency_timer"):
            obj.set_latency_timer(ms)
            return True
        if hasattr(obj, "__dict__"):
            stack.extend(vars(obj).values())
    return False

import os
is_blinka_env_set = os.environ["BLINKA_FT232H"]
print(f"is_blinka_env_set: {is_blinka_env_set}")


import board
import time
import digitalio

import busio

print("--- Full Board Inspection ---")
print(f"board_id: {board.board_id}")
print(f"board_key: {board.board_key}")
print(f"board_module: {board.board_module}")
print(f"pin: {board.pin}")
print(dir(board))


led = digitalio.DigitalInOut(board.C0)
led.direction = digitalio.Direction.OUTPUT


i = 0
while i < 10:
    led.value = False
    time.sleep(0.1)
    led.value = True
    time.sleep(0.1)
    i = i + 1

# Backpack I2C Address (defined in Adafruit docs, and etched on the board)
ADDR = 0x70

print("i2c setup...")
i2c = busio.I2C(board.SCL, board.SDA, frequency=400_000)

while not i2c.try_lock():
    print("trying...")
    pass

if lower_ftdi_latency(i2c, 1):
    print("FTDI latency timer set to 1 ms")
else:
    print("could not reach the FTDI handle; still at 16 ms default")

addresses = i2c.scan()

for x in addresses:
    print(f"-> Device found at address: {hex(x)} (Decimal: {x})")
    if x == ADDR:
        print(f"   *** ADDR {hex(ADDR)} detected! ***")


# I2C slave address of the ADS112C04. This is set by the device's two
# address pins (both tied to GND in this wiring) and confirmed by the bus
# scan coming back with 0x40. It identifies the chip on the bus and is a
# separate thing from the command bytes below.
ADS_ADDR = 0x40

# All command bytes come from the command format in datasheet section 8.5.3.
# Each command is a single byte. Bits shown as x are don't-care, set to 0.

# RESET: format 0000 011x  ->  0000 0110
RESET = 0x06

# RREG, read a register: format 0010 rrxx
# rr is the 2-bit register number sitting in bits 3 and 2. xx are don't-care.
RREG0 = 0x20   # 0010 0000   rr = 00, register 0
RREG1 = 0x24   # 0010 0100   rr = 01, register 1
RREG2 = 0x28   # 0010 1000   rr = 10, register 2
RREG3 = 0x2C   # 0010 1100   rr = 11, register 3

# WREG, write a register: format 0100 rrxx, followed by the data byte.
# Same rr placement as RREG; only the top nibble changes from 0010 to 0100.
WREG0 = 0x40   # 0100 0000   rr = 00, register 0
WREG1 = 0x44   # 0100 0100   rr = 01, register 1
WREG2 = 0x48   # 0100 1000   rr = 10, register 2
WREG3 = 0x4C   # 0100 1100   rr = 11, register 3

def ads_read_reg(i2c, rreg_cmd):
    result = bytearray(1)
    i2c.writeto_then_readfrom(ADS_ADDR, bytes([rreg_cmd]), result)
    return result[0]

def ads_write_reg(i2c, wreg_cmd, value):
    i2c.writeto(ADS_ADDR, bytes([wreg_cmd, value]))

print("i2c resetting...")
i2c.writeto(ADS_ADDR, bytes([RESET]))
print("i2c after reset (expect 0x0):")
print(f"  reg0 -> {hex(ads_read_reg(i2c, RREG0))}")
print(f"  reg1 -> {hex(ads_read_reg(i2c, RREG1))}")
print(f"  reg2 -> {hex(ads_read_reg(i2c, RREG2))}")
print(f"  reg3 -> {hex(ads_read_reg(i2c, RREG3))}")

time.sleep(0.1)

print("i2c writing...")

ads_write_reg(i2c, WREG0, 0x01)
ads_write_reg(i2c, WREG1, 0x04)

print("i2c after writing config:")
print(f"  reg0 -> {hex(ads_read_reg(i2c, RREG0))}")
print(f"  reg1 -> {hex(ads_read_reg(i2c, RREG1))}")

time.sleep(0.1)

START = 0x08    # START/SYNC: 0000 1000, kicks off one conversion
RDATA = 0x10    # RDATA:      0001 0000, reads the latest conversion result

AVDD = 3.3      # set to your measured AVDD pin voltage

def ads_read_data(i2c):
    result = bytearray(2)
    i2c.writeto_then_readfrom(ADS_ADDR, bytes([RDATA]), result)
    return (result[0] << 8) | result[1]     # combine the two bytes into 16 bits

def ads_data_ready(i2c):
    return ads_read_reg(i2c, RREG2) & 0x80   # DRDY is bit 7 of register 2

def ads_read_voltage(i2c):
    i2c.writeto(ADS_ADDR, bytes([START]))    # start one conversion
    while not ads_data_ready(i2c):           # wait until the result is ready
        time.sleep(0.005)
    raw = ads_read_data(i2c)
    if raw & 0x8000:                          # 16-bit two's complement -> signed
        raw -= 0x10000
    return raw * AVDD / 32768                 # scale to volts against the reference

# AIN0 - AIN1, gain 1, PGA bypassed, AVDD as reference
ads_write_reg(i2c, WREG0, 0x01)
ads_write_reg(i2c, WREG1, 0x04)



import threading
import collections
import matplotlib.pyplot as plt
from matplotlib.animation import FuncAnimation

GAIN = 1

# reg0: AIN0-AIN1, gain 1, PGA bypassed
# reg1: 0xDC = turbo, 2000 SPS, continuous conversion, AVDD reference
ads_write_reg(i2c, WREG0, 0x01)
ads_write_reg(i2c, WREG1, 0xDC)
i2c.writeto(ADS_ADDR, bytes([START]))      # start continuous conversions once

def ads_read_latest(i2c):
    raw = ads_read_data(i2c)               # RDATA only: no START, no DRDY poll
    if raw & 0x8000:
        raw -= 0x10000
    return raw * AVDD / GAIN / 32768


last_report = time.monotonic()
read_count = 0
rate = 0.0

data_lock = threading.Lock()
times = collections.deque(maxlen=8000)
volts = collections.deque(maxlen=8000)
start_time = time.monotonic()
running = True
count = 0

def acquire():
    global count
    while running:
        v = ads_read_latest(i2c)
        ts = time.monotonic() - start_time
        with data_lock:
            times.append(ts)
            volts.append(v)
            count += 1

worker = threading.Thread(target=acquire, daemon=True)
worker.start()

WINDOW_SECONDS = 5
plt.style.use("dark_background")
fig, ax = plt.subplots(figsize=(10, 5))
fig.canvas.manager.set_window_title("ADS112C04 live")
(line,) = ax.plot([], [], color="#00e5ff", linewidth=1.5)
rate_text = ax.text(0.02, 0.95, "", transform=ax.transAxes,
                    fontsize=16, color="#00e5ff", va="top")
ax.set_xlabel("time (s)")
ax.set_ylabel("volts")
ax.set_ylim(0, 1.8)
ax.grid(True, alpha=0.2)
fig.tight_layout()

last_t = time.monotonic()
last_count = 0

def update(_):
    global last_t, last_count
    with data_lock:
        t = list(times)
        v = list(volts)
        c = count
    line.set_data(t, v)
    if t:
        ax.set_xlim(max(0, t[-1] - WINDOW_SECONDS), max(WINDOW_SECONDS, t[-1]))
    now = time.monotonic()
    dt = now - last_t
    sps = (c - last_count) / dt if dt > 0 else 0
    last_t, last_count = now, c
    rate_text.set_text(f"{v[-1]:.4f} V    {sps:.0f} samples/s" if v else "")
    return (line, rate_text)

ani = FuncAnimation(fig, update, interval=33, blit=False, cache_frame_data=False)
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

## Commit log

2026-07-04 Add initial README for pcb-100mm-slider-i2c
2026-09-07 Add KiCanvas interactive viewers for schematic and PCB
2026-09-07 Fix 3D camera auto-framing based on bounding box
2026-09-07 Set 3D viewer initial camera to top-down
2026-09-07 Fix camera to look at the top face of the board
2026-09-07 Fix camera to point at correct board face
2026-09-07 Fix slight camera tilt by explicitly defining up-vector
2026-09-07 Enable logarithmic depth buffer to fix silkscreen z-fighting
2026-09-07 Apply texture anisotropy and alpha testing to fix silkscreen rendering
2026-09-07 Improve styling of demo description and add PCB thumbnail
